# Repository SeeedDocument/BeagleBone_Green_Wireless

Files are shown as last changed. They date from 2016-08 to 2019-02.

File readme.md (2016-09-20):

BeagleBone Green Wireless
---

**SKU**: [102010048](http://www.seeedstudio.com/SeeedStudio-BeagleBone-Green-Wireless-p-2650.html)

**Wiki Link**: [wiki.seeed.cc](wiki.seeed.cc)

###Change Log:

- **2016-8-28:** update and create repos by Jerry Yip

--------
This document is written by Seeed Studio and is licensed under MIT License.

Contributing to this document is warmly welcomed. You can do this basically by
[forking](https://help.github.com/articles/fork-a-repo), committing modifications and then [pulling requests](https://help.github.com/articles/using-pull-requests) (follow the links above
for operating guide). Adding change log and your contact into file header is encouraged.
Thanks for your contribution.

Seeed is a hardware innovation platform for makers to grow inspirations into differentiating products. By working closely with technology providers of all scale, Seeed provides accessible technologies with quality, speed and supply chain knowledge. When prototypes are ready to iterate, Seeed helps productize 1 to 1,000 pcs using in-house engineering, supply chain management and agile manufacture forces. Seeed also team up with incubators, Chinese tech ecosystem, investors and distribution channels to portal Maker startups beyond.

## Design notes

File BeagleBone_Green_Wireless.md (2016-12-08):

---
title: BeagleBone Green Wireless
category: BeagleBone, IoT
bzurl: https://www.seeedstudio.com/SeeedStudio-BeagleBone-Green-Wireless-p-2650.html
oldwikiname: SeeedStudio_BeagleBone_Green_Wireless
prodimagename: BBGW_cover.png
surveyurl: https://www.surveymonkey.com/r/bbg_w
sku: 102010048
---

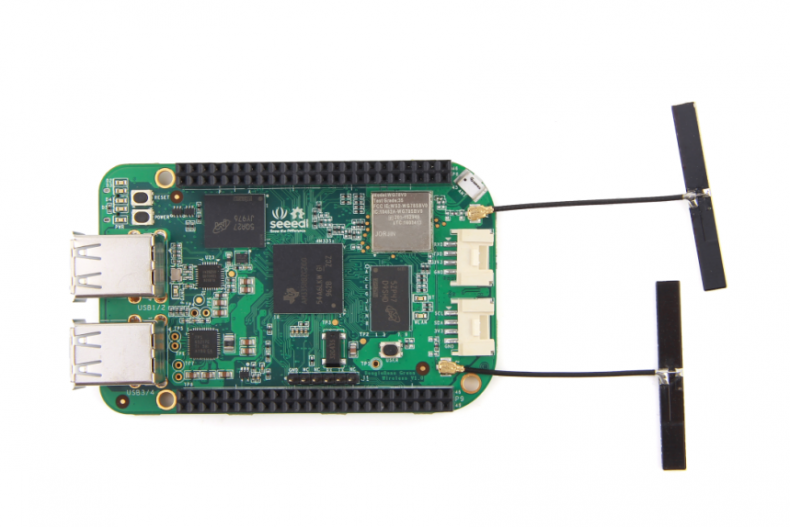
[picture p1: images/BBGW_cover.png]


SeeedStudio BeagleBone Green Wireless (BBGW) is a joint effort by [BeagleBoard.org](http://beagleboard.org) and Seeed Studio. It is based on the open-source hardware design of [BeagleBone Black](http://beagleboard.org/black) and developed into this differentiated version. SeeedStudio BeagleBone Green Wireless has included a high-performance flexible WiFi/Bluetooth interface and two Grove connectors, making it easier to connect to the large family of Grove sensors. The on-board HDMI and Ethernet are removed to make room for these wireless features and Grove connectors.

(http://www.seeedstudio.com/SeeedStudio-BeagleBone-Green-Wireless-p-2650.html)

## Features
----

* **Fully Compatiable with BeagleBone Black**
* **Processor: AM335x 1GHz ARM® Cortex-A8**
	* 512MB DDR3 RAM
	* 4GB 8-bit eMMC on-board flash storage
	* 3D graphics accelerator
	* NEON floating-point accelerator
	* 2x PRU 32-bit microcontrollers

* **Connectivity**
	* USB client for power & communications
	* USB host with 4-port hub
	* WiFi 802.11 b/g/n 2.4GHz
	* Bluetooth 4.1 with BLE
	* 2x 46 pin headers
	* 2x Grove connectors (I2C and UART)

* **Software Compatibility**
	* Debian
	* Android
	* Ubuntu
	* Cloud9 IDE on Node.js w/ BoneScript library
	* plus much more

## Specification
----

|Item|Value|
|----|---|
|Processor|	AM335x 1GHz ARMR Cortex-A8|
|RAM|	512MB DDR3|
|on-board Flash Storage	|4GB eMMC|
|CPU Supports	|NEON floating-point & 3D graphics accelerator|
|Micro USB	Supports |powering & communications|
|USB |USB2.0 Host	*4|
|Grove Connectors	|2 (One I2C and One UART) |
|GPIO	|2 x 46 pin headers|
|Ethernet	|Wi-Fi 802.11b/g/n 2.4GHz and Bluetooth 4.1 LE|
|Operating Temperature	|0 ~ 75 |

## Application Ideas
- Internet of Things
- Smart House
- Industrial
- Automation & Process Control
- Human Machine Interface
- Sensor Hub
- Robot

###BBGW Starter Tutorial #1-#6
Here are some tutorials for the starters to use some Grove modules to realize their interesting ideas with BeagleBone Green Wireless(BBGW). The tutorials are based on Python and mraa/upm library.  

|#1 The Breath LED|#2 Storm on your table|#3 Speak Louuuuuudly|
|---|-----|---|
||||
|[MAKE IT NOW!](http://www.seeed.cc/BBGW-starter-tutorial%231-The-breath-LED-p-1641.html)|[MAKE IT NOW!](http://www.seeed.cc/BBGW-starter-tutorial%232%3A-storm-on-your-table-p-1643.html)|[MAKE IT NOW!](http://www.seeed.cc/BBGW-starter-tutorial%233-Speak-louuuuuudly-p-1644.html)|

|#4 How hot is it today?|#5 Where are you?|#6 My Little alarm clock|
|---|-----|---|
||||
|[MAKE IT NOW!](http://www.seeed.cc/BBGW-starter-tutorial%234%3AHow-hot-is-it-today%3F-Ask-BBGW!-p-1645.html)|[MAKE IT NOW!](http://www.seeed.cc/BBGW-starter-tutorial%235-Where-are-you%3F-p-1648.html)|[MAKE IT NOW!](http://www.seeed.cc/BBGW-starter-tutorial%236-My-little-alarm-clock-p-1646.html)|

###Funny Projects

|Bluetooth Device Detection|Home Control Center|SAP HCP IoT Service|
|---|-----|---|
||||
|[MAKE IT NOW!](http://www.seeed.cc/Bluetooth-Device-Detection-with-the-BeagleBone-Green-Wireless-p-1601.html)|[MAKE IT NOW!](http://www.seeed.cc/Home-Control-Center-using-BeagleBone-Green-Wireless-p-1596.html)|[MAKE IT NOW!](http://www.seeed.cc/SAP-HCP-IOT-SERVICE-WITH-WIOLINK-p-1581.html)|

## Hardware Overview

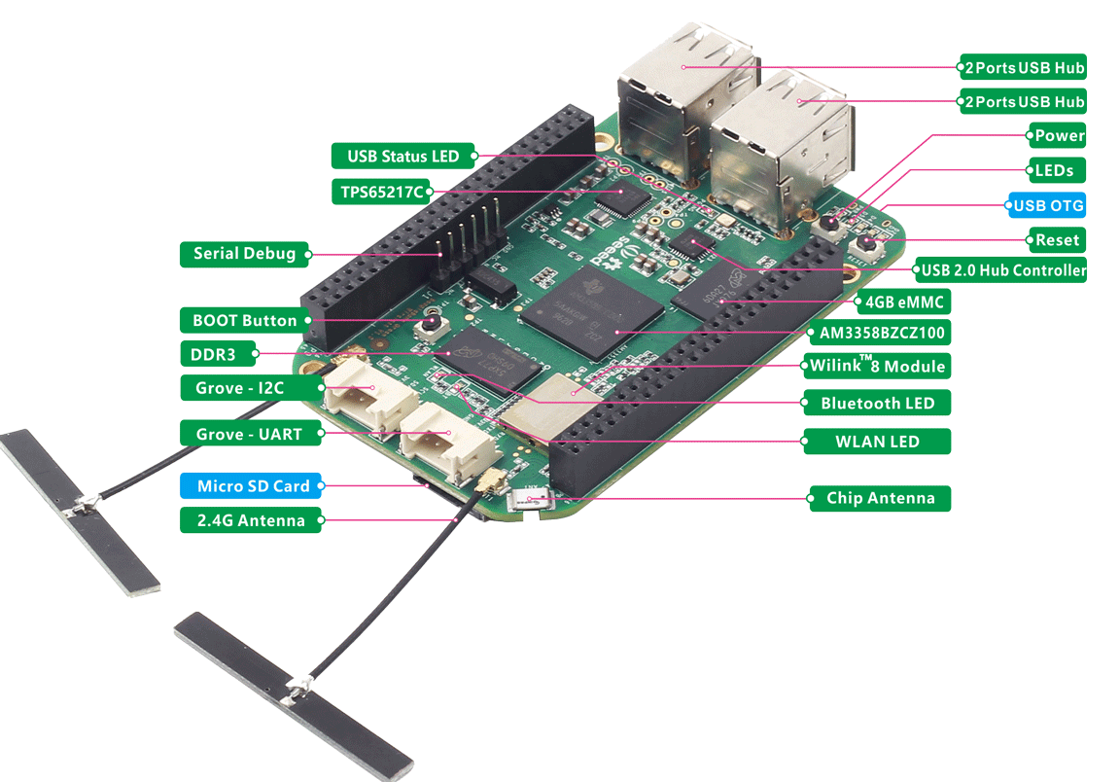
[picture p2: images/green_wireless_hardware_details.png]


###Pin map

Each digital I/O pin has 8 different modes that can be selected, including GPIO.

####65 Possible Digital I/Os

!!!Note
    In GPIO mode, each digital I/O can produce interrupts.

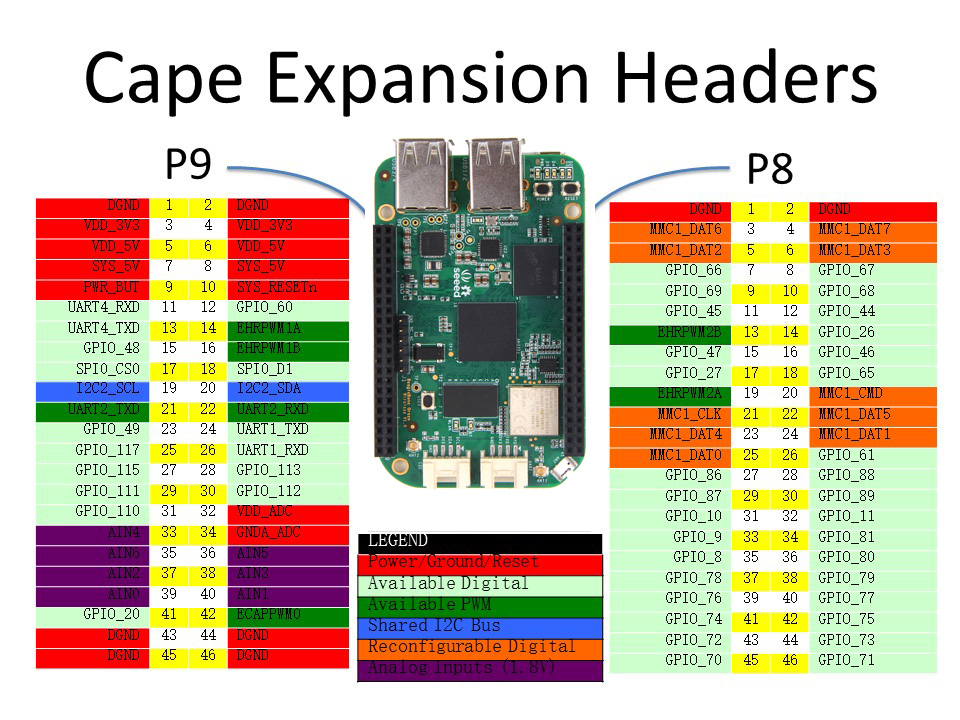
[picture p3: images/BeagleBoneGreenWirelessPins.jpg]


####PWMs and Timers

!!!Note
    Up to 8 digital I/O pins can be configured with pulse-width modulators (PWM) to produce signals to control motors or create pseudo analog voltage levels, without taking up any extra CPU cycles.

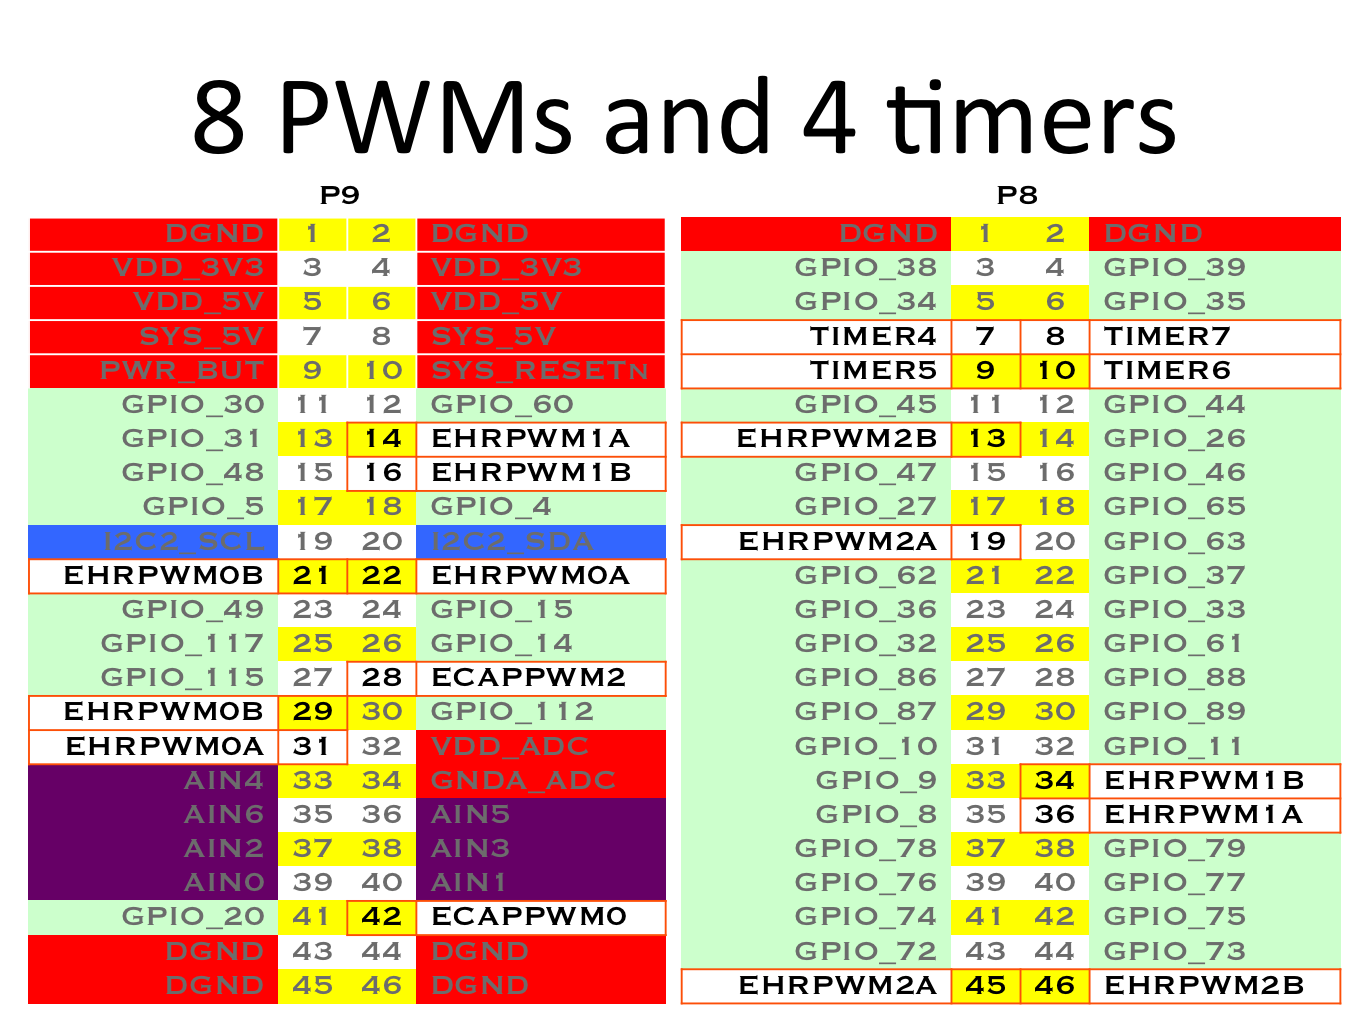
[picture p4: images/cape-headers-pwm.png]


####Analog Inputs

!!!Note
    Make sure you don't input more than 1.8V to the analog input pins. This is a single 12-bit analog-to-digital converter with 8 channels, 7 of which are made available on the headers.

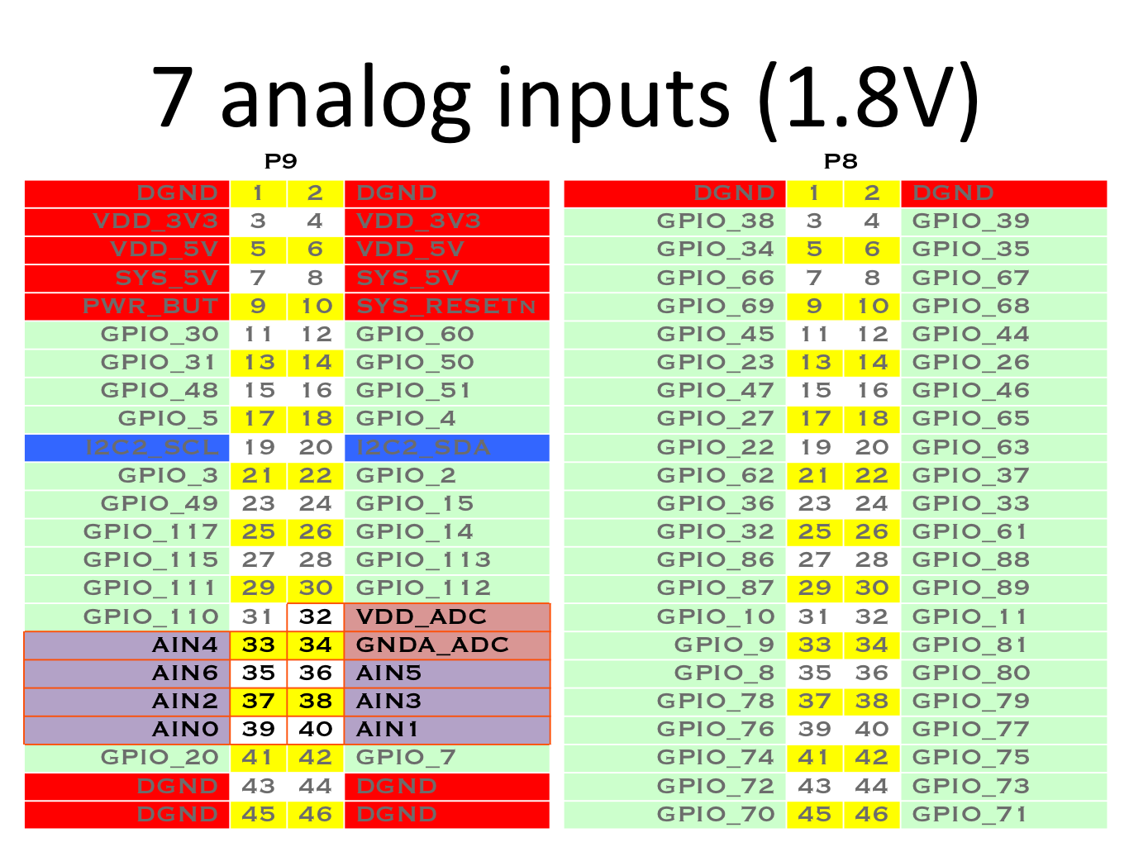
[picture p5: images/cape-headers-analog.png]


####UART

!!!Note
    There is a dedicated header for getting to the UART0 pins and connecting a debug cable. Five additional serial ports are brought to the expansion headers, but one of them only has a single direction brought to the headers.

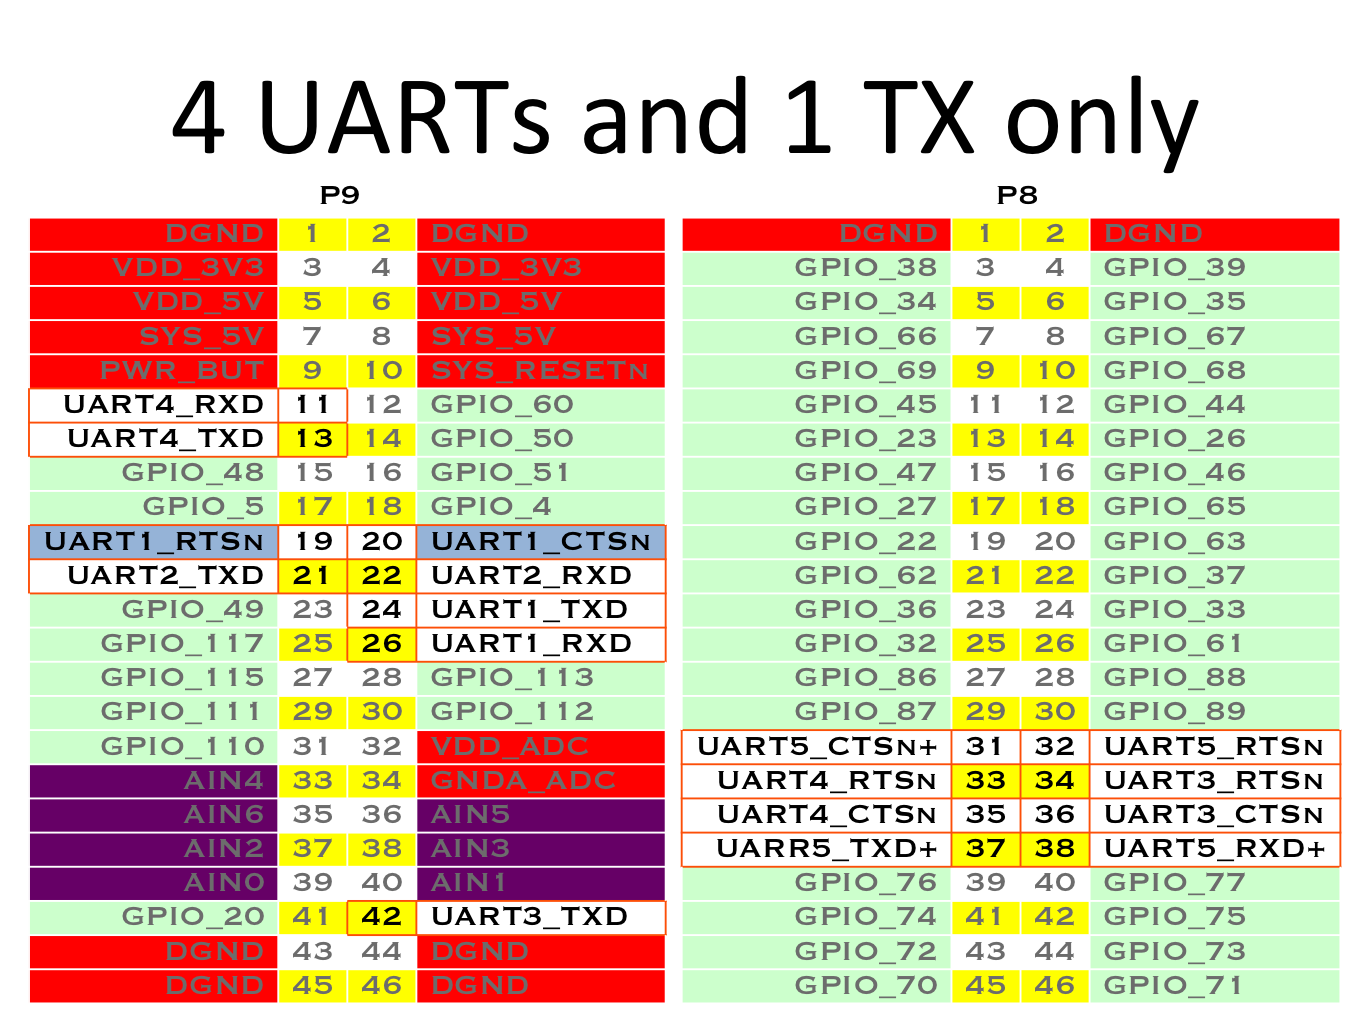
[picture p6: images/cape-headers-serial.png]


####I2C

!!!Note
    The first I2C bus is utilized for reading EEPROMS on cape add-on boards and can't be used for other digital I/O operations without interfering with that function, but you can still use it to add other I2C devices at available addresses. The second I2C bus is available for you to configure and use.

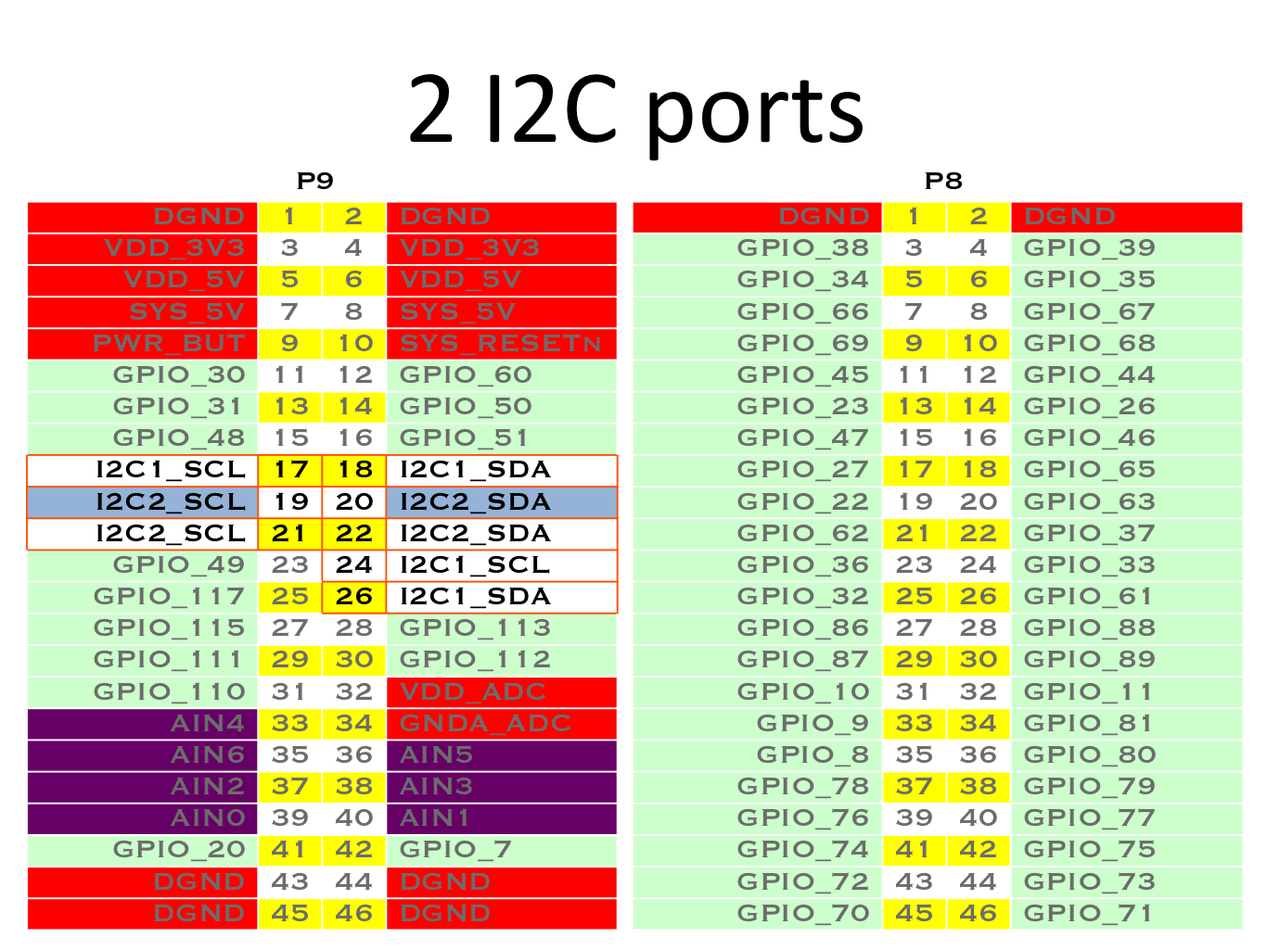
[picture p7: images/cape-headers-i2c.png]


####SPI

!!!Note
    For shifting out data fast, you might consider using one of the SPI ports.

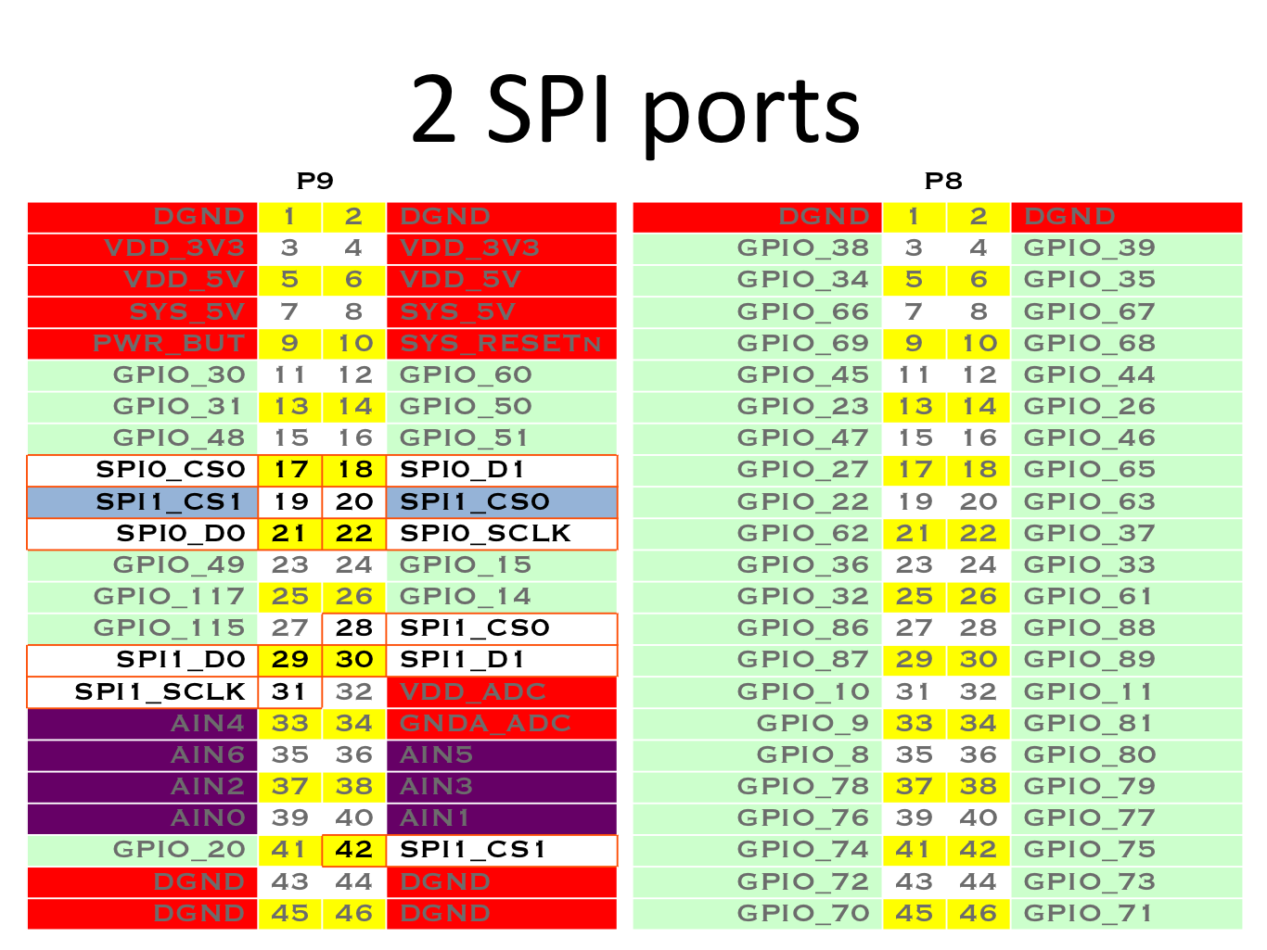
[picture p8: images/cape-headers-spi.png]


## Getting Started
----

!!!Note
    This chapter is writing under Win10. The steps are familiar for the other operate systems.

###STEP1. Plug in your BBGW via USB
Use the provided micro USB cable to plug your BBGW into your computer. This will both power the board and provide a development interface. BBGW will boot Linux from the **on-board 2GB** or 4GB eMMC.

BBGW will operate as a flash drive providing you with a local copy of the documentation and drivers. Note that this interface may not be used to re-configure the microSD card with a new image, but may be used to update the boot parameters using the uEnv.txt file.

You’ll see the PWR LED lit steadily. Within 10 seconds, you should see the other LEDs blinking in their default configurations.

- D2 is configured at boot to blink in a heartbeat pattern
- D3 is configured at boot to light during microSD card accesses
- D4 is configured at boot to light during CPU activity
- D5 is configured at boot to light during eMMC accesses

###STEP2. Install Drivers

Install the drivers for your operating system to give you network-over-USB access to your Beagle. Additional drivers give you serial access to your board.

|Operating System |	USB Drivers |	Comments |
|---|---|---|
|Windows (64-bit) |	[64-bit installer](http://beagleboard.org/static/Drivers/Windows/BONE_D64.exe)	 | |
|Windows (32-bit) |	[32-bit installer](http://beagleboard.org/static/Drivers/Windows/BONE_DRV.exe)||
|Mac OS X|[Network](http://beagleboard.org/static/Drivers/MacOSX/RNDIS/HoRNDIS.pkg) [Serial](http://beagleboard.org/static/Drivers/MacOSX/FTDI/EnergiaFTDIDrivers2.2.18.pkg) | Install both sets of drivers.|
|Linux|[mkudevrule.sh](http://beagleboard.org/static/Drivers/Linux/FTDI/mkudevrule.sh)|Driver installation isn't required, but you might find a few udev rules helpful.|

!!!Note
    For window system, please note that:

    * Windows Driver Certification warning may pop up two or three times. Click "Ignore", "Install" or "Run"
    * To check if you're running 32 or 64-bit Windows see [this](https://support.microsoft.com/kb/827218).
    *  On systems without the latest service release, you may get an error (0xc000007b). In that case, please [install](https://www.microsoft.com/en-us/download/confirmation.aspx?id=13523) and retry:
    * You may need to reboot Windows.
    * These drivers have been tested to work up to Windows 10

###STEP3. Browse to your Beagle

Using either Chrome or Firefox (Internet Explorer will NOT work), browse to the web server running on your board. It will load a presentation showing you the capabilities of the board. Use the arrow keys on your keyboard to navigate the presentation.

Click [http://192.168.7.2](http://192.168.7.2) to launch to your BBGW.
Older software images require you to EJECT the BEAGLE_BONE drive to start the network. With the latest software image, that step is no longer required.

Click to view larger image

###STEP4. Cloud9 IDE

To begin editing programs that live on your board, you can use the Cloud9 IDE by click

(http://192.168.7.2:3000/ide.html)

###STEP5. Connect your BBGW to Wi-Fi

Using your smart phone or computer to scan local Wi-Fi network and connect to the AP named "BeagleBone XXX"

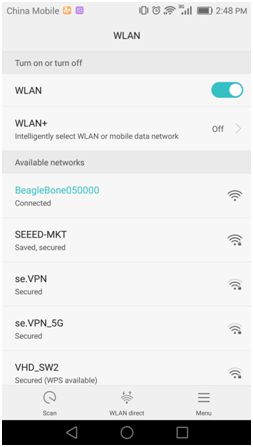
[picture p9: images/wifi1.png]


After connection succeeded, it will head to the login page automatically. Select the SSID of your Wi-Fi and enter the passwd, click OK.

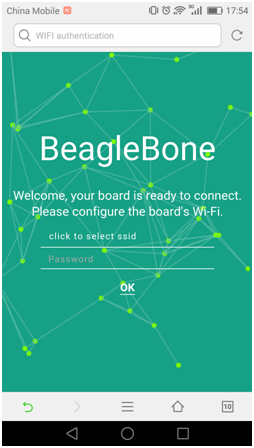
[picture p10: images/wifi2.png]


Now your BBGW is connected to Wi-Fi.

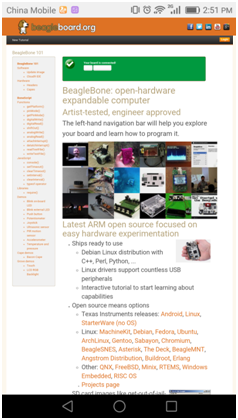
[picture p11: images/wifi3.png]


###STEP6. Connect your BBGW to your Bluetooth Device

Connect to Cloud9 IDE and start a new terminal.
Start the bluetooth config with the command:

```
bb-wl18x-bluetooth
bluetoothctl
```

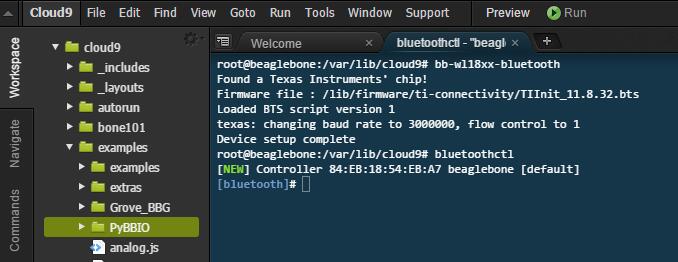
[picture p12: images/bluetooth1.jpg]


Type ``scan on`` to scan local bluetooth devices. My device named "jy" is found.

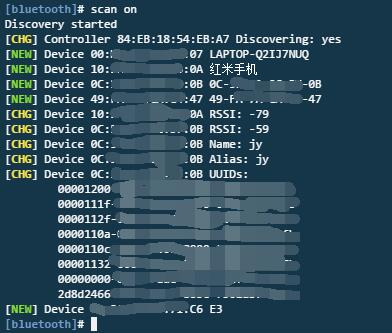
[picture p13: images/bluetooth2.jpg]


Copy the device mac address, then contect to the device  with the command:

```
pair 0C:xx:xx:xx:xx:0B
trust 0C:xx:xx:xx:xx:0B
connect 0C:xx:xx:xx:xx:0B
```

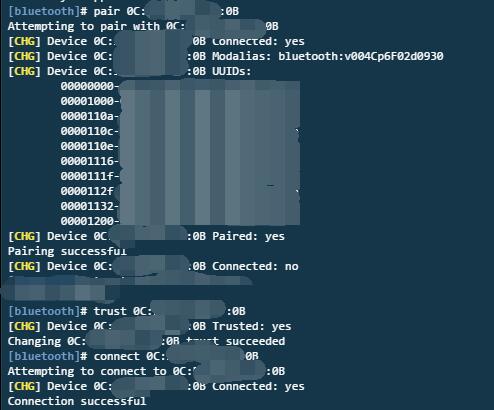
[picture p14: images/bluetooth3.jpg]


Now your BBGW is connected to your bluetooth device. Type ``quit`` back to the terminal.
Play music on BBGW, then you will hear music on your bluetooth speaker device.

## Update to latest software
-----

You need to update the board to latest software to keep a better performance, here we will show you how to make it step by step.

###STEP1. Download the latest software image

First of all, you have to download the suitable image here.

(https://www.dropbox.com/s/9qsa75cazhjgb1x/BBGW-blank-debian-8.4-seeed-iot-armhf-2016-06-27-4gb1.zip?dl=0)

!!!Note
    Due to sizing necessities, this download may take about 30 minutes or more.

The file you download will have an **.img.xz** extension. This is a compressed sector-by-sector image of the SD card.

###STEP2. Install compression utility and decompress the image

Download and install [7-zip.](http://www.7-zip.org/download.html)

!!!Note
    Choose a version that suitable for your system.

Use 7-zip to decompress the SD card **.img file**

###STEP3. Install SD card programming utility

Download and install [Image Writer for Windows](https://sourceforge.net/projects/win32diskimager/files/latest/download). Be sure to download the binary distribution.

###STEP4. Write the image to your SD card

You need a SD adapter to connect your microSD card to your computer at the first. Then use the software Image Write for Windows to write the decompressed image to your SD card.



Click on **Write** button, then the process is started.



!!!Note
    * You may see a warning about damaging your device. This is fine to accept as long as you are pointing to your SD card for writing.
    * You should not have your BeagleBone connected to your computer at this time.
    * This process may need up to 10 minutes.

###STEP5. Boot your board off of the SD card

Insert SD card into your (powered-down first) board. Then the board will boot from the SD card.

!!!Note
    If you don't need to write the image to your on-board eMMC, you don't need to read the last of this chapter.  Otherwise pleas go ahead.

If you desire to write the image to your on-board eMMC, you need to launch to the board, and modify a file.

In **/boot/uEnv.txt**:

    ##enable Generic eMMC Flasher:
    ##make sure, these tools are installed: dosfstools rsync
    #cmdline=init=/opt/scripts/tools/eMMC/init-eMMC-flasher-v3.sh
    
Change to:

    ##enable Generic eMMC Flasher:
    ##make sure, these tools are installed: dosfstools rsync
    cmdline=init=/opt/scripts/tools/eMMC/init-eMMC-flasher-v3.sh

Then you will find the 4 user led light as below:



!!!Note
    If you don't find the upper tracing light, please power down and power up the board.

When the flashing is complete, all 4 USRx LEDs will be **off**. The latest Debian flasher images automatically power down the board upon completion. This can take up to **10 minutes**. Power-down your board, remove the SD card and apply power again to be complete.

## Program Grove Module with Mraa and UPM

We have provided Mraa library and UPM library to make it easy for developers and sensor manufacturers to map their sensors & actuators on top of supported hardware and to allow control of low level communication protocol by high level languages & constructs.
###What are Mraa and UPM?
Mraa is a C/C++ library with bindings to Python, Javascript and Java to interface with the I/O on BBG, BBGW and other platforms, with a structured and sane API where port names/numbering matches the board that you are on. Use of Mraa does not tie you to specific hardware with board detection done at runtime you can create portable code that will work across the supported platforms.
UPM is a high level repository for sensors that use MRAA. Each sensor links to MRAA and are not meant to be interlinked although some groups of sensors may be. Each sensor contains a header which allows to interface with it. Typically a sensor is represented as a class and instantiated.The constructor is expected to initialise the sensor and parameters may be used to provide identification/pin location on the board.

###Install and update
Mraa and UPM are already installed in the system image of BBGW, so **you don't need to install it.** However if you want to update the library, or want to upgrade the library, use ``apt-get update`` and ``apt-get upgrade`` please. Refer to [https://github.com/intel-iot-devkit/mraa](https://github.com/intel-iot-devkit/mraa) and [https://github.com/intel-iot-devkit/upm](https://github.com/intel-iot-devkit/upm) for more information.

###Mraa Example

- light a led

```
import mraa
import time
#mraa.gpio60 = P9_14 = GPIO_50
led = mraa.Gpio(60)
led.dir(mraa.DIR_OUT)

while True:
    led.write(1)
    time.sleep(1)
    led.write(0)
    time.sleep(1)

```

- Grove - PIR Sensor

```
import mraa
import time
#mraa.gpio73 = P9_27 = GPIO_115
pir = mraa.Gpio(73)
pir.dir(mraa.DIR_IN)

while True:
    print (pir.read())
    time.sleep(1)
```

- Grove - Rotary Angle Sensor

```
import mraa
import time
#mraa.aio1 = AIN0
rotary = mraa.Aio(1)

while True:
    print(rotary.read())
    time.sleep(1)
```

- More Tutorials

[Grove - 3-Axis Digital Accelerometer(±16g)
 Grove - Variable Color LED](http://www.seeed.cc/BBGW-starter-tutorial%231-The-breath-LED-p-1641.html)

[Grove - Mini Fan
Grove - PIR Motion Sensor
Grove - Rotary Angle Sensor
](http://www.seeed.cc/BBGW-starter-tutorial%232%3A-storm-on-your-table-p-1643.html)

[Grove - Relay
Grove - Sound Sensor
](http://www.seeed.cc/BBGW-starter-tutorial%233-Speak-louuuuuudly-p-1644.html)

[Grove - OLED Display 0.96”
Grove - Light Sensor
Grove - Temperature Sensor
](http://www.seeed.cc/BBGW-starter-tutorial%234%3AHow-hot-is-it-today%3F-Ask-BBGW!-p-1645.html)

[Grove - GPS
Grove - Button(P)
Grove - Buzzer
Grove - RTC v2.0
](http://www.seeed.cc/BBGW-starter-tutorial%235-Where-are-you%3F-p-1648.html)

###Mraa Map for BBGW

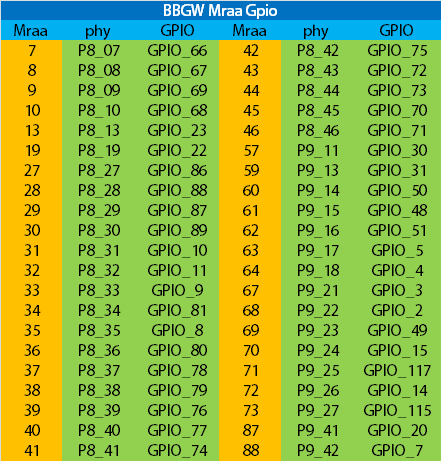
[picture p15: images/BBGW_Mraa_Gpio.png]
GPIO


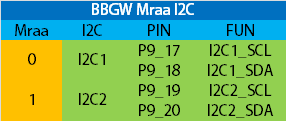
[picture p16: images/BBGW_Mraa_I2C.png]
I2C


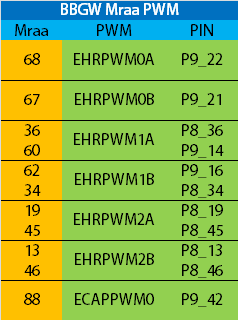
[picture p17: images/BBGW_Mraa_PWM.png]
PWM


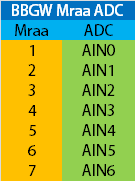
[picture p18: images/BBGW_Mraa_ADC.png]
ADC_IN


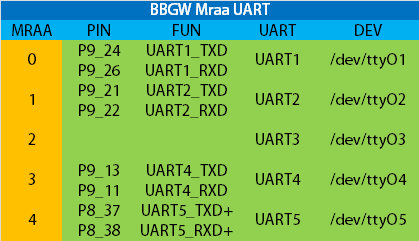
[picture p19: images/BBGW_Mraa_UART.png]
UART


## References and Resources
###References
----
There're many references to help you to get more information about the board.

* [BeagleBoard Main Page](http://beagleboard.org/)
* [BeagleBone Green Wireless info at BeagleBoard page](http://beagleboard.org/green-wireless)
* [BeagleBoard Getting Started](http://beagleboard.org/getting-started)
* [Troubleshooting](http://beagleboard.org/getting-started#troubleshooting)
* [Hardware documentation](http://beagleboard.org/getting-started#hardware)
* [Projects of BeagleBoard](http://beagleboard.org/project)

## Resources
-----
- [BeagleBone_Green_Wireless Schematic(pdf)](https://github.com/SeeedDocument/BeagleBone_Green_Wireless/tree/master/resources/BeagleBone_Green Wireless_V1.0_SCH_20160314.pdf)

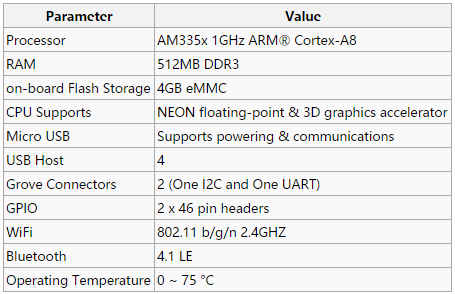
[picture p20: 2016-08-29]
images/BBGW_Specification.png

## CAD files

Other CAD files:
resources/BBGW_0421.skp

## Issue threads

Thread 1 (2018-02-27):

GPIO 60

comarius, 2018-02-27:
Bought 2 of them. They both put the GPIO_60 to 1 2 3 seconds after the prompt >

Boot it from eMMC, and then from SDcard (same behavior).

git:/opt/scripts/:[ea6ea9fca05f36f5044398884375b0231348d6e2]
eeprom:[A335BNLTGW1ABBGW16054396]
model:[TI_AM335x_BeagleBone_Green_Wireless]
dogtag:[BeagleBoard.org Debian Image 2018-01-28]
bootloader:[microSD-(push-button)]:[/dev/mmcblk0]:[U-Boot 2018.01-00002-g9aa111a004]
kernel:[4.9.78-ti-r94]
uboot_overlay_options:[enable_uboot_overlays=1]
uboot_overlay_options:[disable_uboot_overlay_emmc=1]
uboot_overlay_options:[disable_uboot_overlay_video=1]
uboot_overlay_options:[disable_uboot_overlay_audio=1]
uboot_overlay_options:[enable_uboot_cape_universal=1]
pkg:[bb-cape-overlays]:[4.4.20180126.0-0rcnee0~stretch+20180126]
pkg:[bb-wl18xx-firmware]:[1.20170829-0rcnee2~stretch+20180104]
pkg:[firmware-ti-connectivity]:[20170823-1rcnee0~stretch+20170830]
groups:[debian : debian adm kmem dialout cdrom floppy audio dip video plugdev users systemd-journal i2c bluetooth netdev cloud9ide gpio pwm eqep admin spi tisdk weston-launch xenomai]
dmesg | grep pinctrl-single
[    1.489922] pinctrl-single 44e10800.pinmux: 142 pins at pa f9e10800 size 568
END

me@beaglebone:/sys/class/gpio$ ls gpio6*
me@beaglebone:/sys/class/gpio$ find -name gpio60

me@beaglebone:/sys/class/gpio$ config-pin -l P9_60
Invalid pin: "P9_60" "9_60"
Pin is not modifyable: P9_60
# the one side of it works, all others work.
me@beaglebone:/sys/class/gpio$ config-pin -l P9_30
default gpio gpio_pu gpio_pd gpio_input spi pwm pruout pruin

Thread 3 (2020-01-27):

Missing schematic file !

salmanfarisvp, 2020-01-27:
Can't find the schematic file in the [https://github.com/SeeedDocument/BeagleBone_Green_Wireless/blob/master/resources/BeagleBone_Green%20Wireless_V1.0_SCH_20160314.pdf](https://github.com/SeeedDocument/BeagleBone_Green_Wireless/blob/master/resources/BeagleBone_Green%20Wireless_V1.0_SCH_20160314.pdf)

hulkco, 2020-01-27:
Hi @salmanfarisvp, I can see the PDF file.

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

salmanfarisvp, 2020-01-29:
I saw that but can't find the .sch eagle source file.

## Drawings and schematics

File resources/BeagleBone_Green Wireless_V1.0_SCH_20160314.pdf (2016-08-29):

1
3

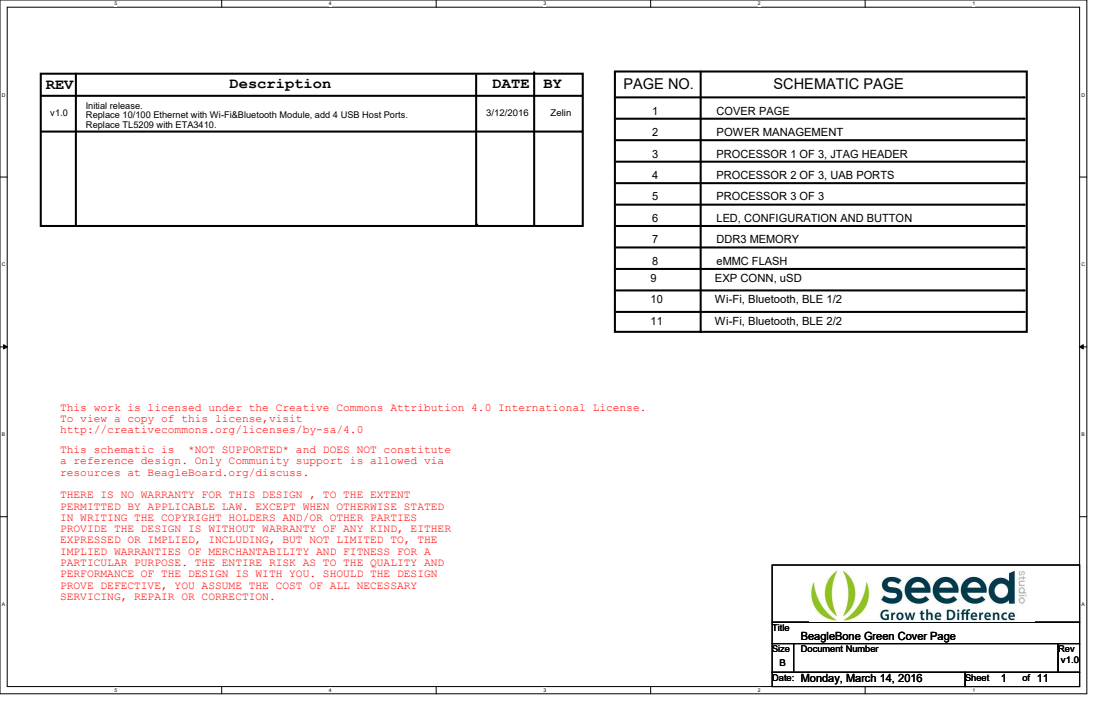
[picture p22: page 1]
eMMC FLASH; PAGE NO.; SCHEMATIC PAGE; REV; Description; DATE; Zelin; Title; Size Document Number; Rev; Date:; Sheet; BeagleBone Green Cover Page; Monday, March 14, 2016

Initial release.
Replace 10/100 Ethernet with Wi-Fi&Bluetooth Module, add 4 USB Host Ports.
Replace TL5209 with ETA3410.

COVER PAGE
POWER MANAGEMENT
PROCESSOR 1 OF 3, JTAG HEADER
PROCESSOR 2 OF 3, UAB PORTS
PROCESSOR 3 OF 3
LED, CONFIGURATION AND BUTTON
DDR3 MEMORY
EXP CONN, uSD
10 Wi-Fi, Bluetooth, BLE 1/2
11 Wi-Fi, Bluetooth, BLE 2/2

This work is licensed under the Creative Commons Attribution 4.0 International License.
To view a copy of this license,visit
http://creativecommons.org/licenses/by-sa/4.0
This schematic is *NOT SUPPORTED* and DOES NOT constitute
a reference design. Only Community support is allowed via
resources at BeagleBoard.org/discuss.
THERE IS NO WARRANTY FOR THIS DESIGN , TO THE EXTENT
PERMITTED BY APPLICABLE LAW. EXCEPT WHEN OTHERWISE STATED
IN WRITING THE COPYRIGHT HOLDERS AND/OR OTHER PARTIES
PROVIDE THE DESIGN IS WITHOUT WARRANTY OF ANY KIND, EITHER
EXPRESSED OR IMPLIED, INCLUDING, BUT NOT LIMITED TO, THE
IMPLIED WARRANTIES OF MERCHANTABILITY AND FITNESS FOR A
PARTICULAR PURPOSE. THE ENTIRE RISK AS TO THE QUALITY AND
PERFORMANCE OF THE DESIGN IS WITH YOU. SHOULD THE DESIGN
PROVE DEFECTIVE, YOU ASSUME THE COST OF ALL NECESSARY
SERVICING, REPAIR OR CORRECTION.

Title
BeagleBone Green Cover Page

# Battery access pins. Pins are randomly placed to fit

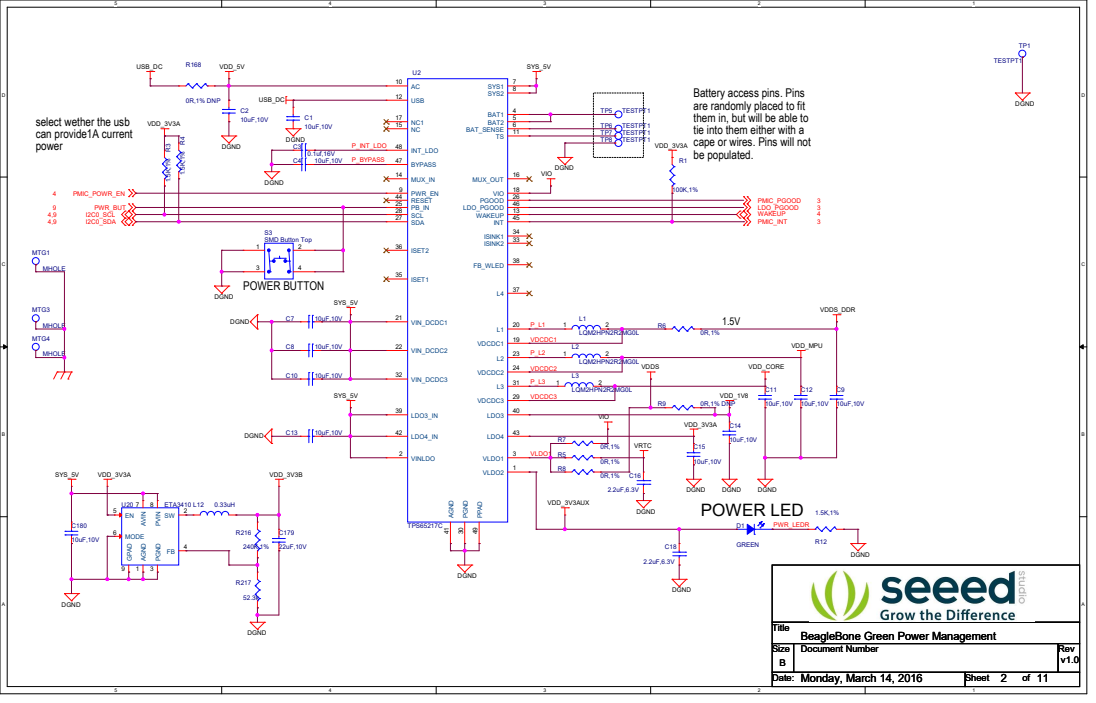
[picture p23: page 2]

them in, but will be able to
tie into them either with a
cape or wires. Pins will not
VDD_3V3A
be populated.

# RESET

3.3V

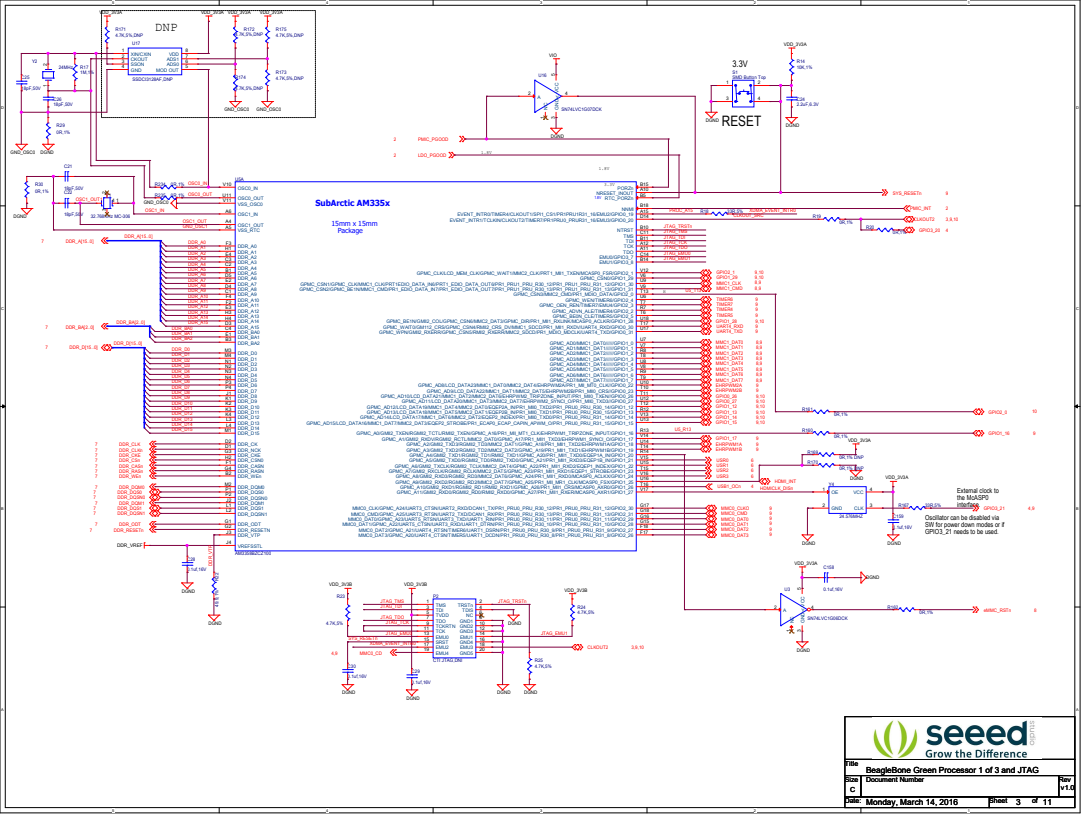
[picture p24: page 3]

PORZn B15 NRESET_INOUT A10 NNMI B18 EVENT_INTR0/TIMER4/CLKOUT1/SPI1_CS1/PR1PRU1R31_16/EMU2/GPIO0_19 A15 EVENT_INTR1/TCLKIN/CLKOUT2/TIMER7/PR1PRU0_PRUR31_16/EMU3/GPIO0_20 D14 TMS C11 NTRST B10 TCK A12 TDI B11 TDO A11 EMU0/GPIO3_7 C14 DDR_A0 F3 DDR_A1 H1 DDR_A2 E4 DDR_A3 C3 DDR_A4 C2 DDR_A5 B1 DDR_A6 D5 DDR_A7 E2 DDR_A8 D4 DDR_A9 C1 DDR_A10 F4 DDR_A11 F2 DDR_A12 E3 DDR_A13 H3 DDR_A14 H4 DDR_D0 M3 DDR_D1 M4 DDR_D2 N1 DDR_D3 N2 DDR_D4 N3 DDR_D5 N4 DDR_D6 P3 DDR_D7 P4 DDR_D8 J1 DDR_D9 K1 DDR_D10 K2 DDR_D11 K3 DDR_D12 K4 DDR_D13 L3 DDR_D14 L4 DDR_D15 M1 DDR_CK D2 DDR_NCK D1 DDR_CSN0 H2 DDR_CASN F1 DDR_RASN G4 DDR_WEn B2 DDR_BA0 C4 DDR_BA1 E1 DDR_BA2 B3 DDR_DQM0 M2 DDR_DQS0 P1 DDR_DQSN0 P2 DDR_DQM1 J2 DDR_DQS1 L1 DDR_DQSN1 L2 DDR_ODT G1

Oscillator can be disabled via
SW for power down modes or if
GPIO3_21 needs to be used.

# VDD_ADC GNDA_ADC

# VDD_3V3B DGND

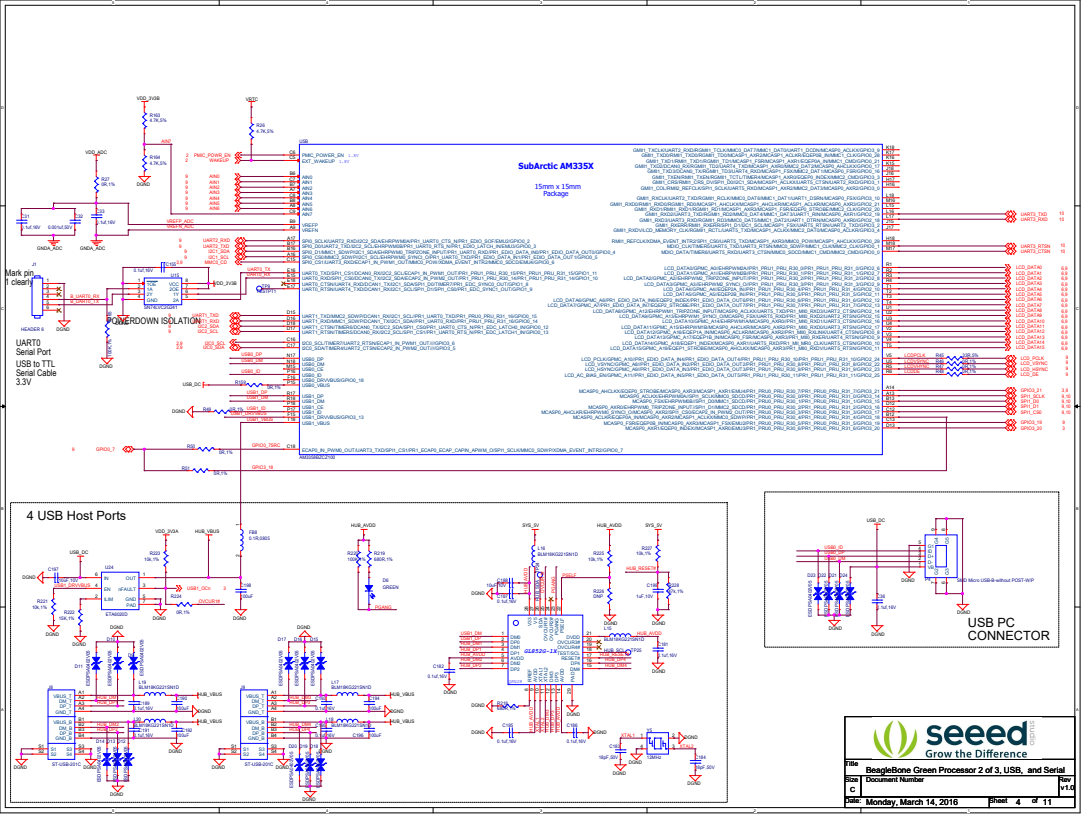
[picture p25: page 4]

9 XTAL1 10 XTAL2 11 DM3 12 DP3 13 AVDD 14 V33 28 V5 27 SDA 26 OVCUR1# 25 OVCUR2# 24 PGANG 23 PSELF 22 PAD 29

# 0.1uf,16V C38

# 0.1uf,16V C74

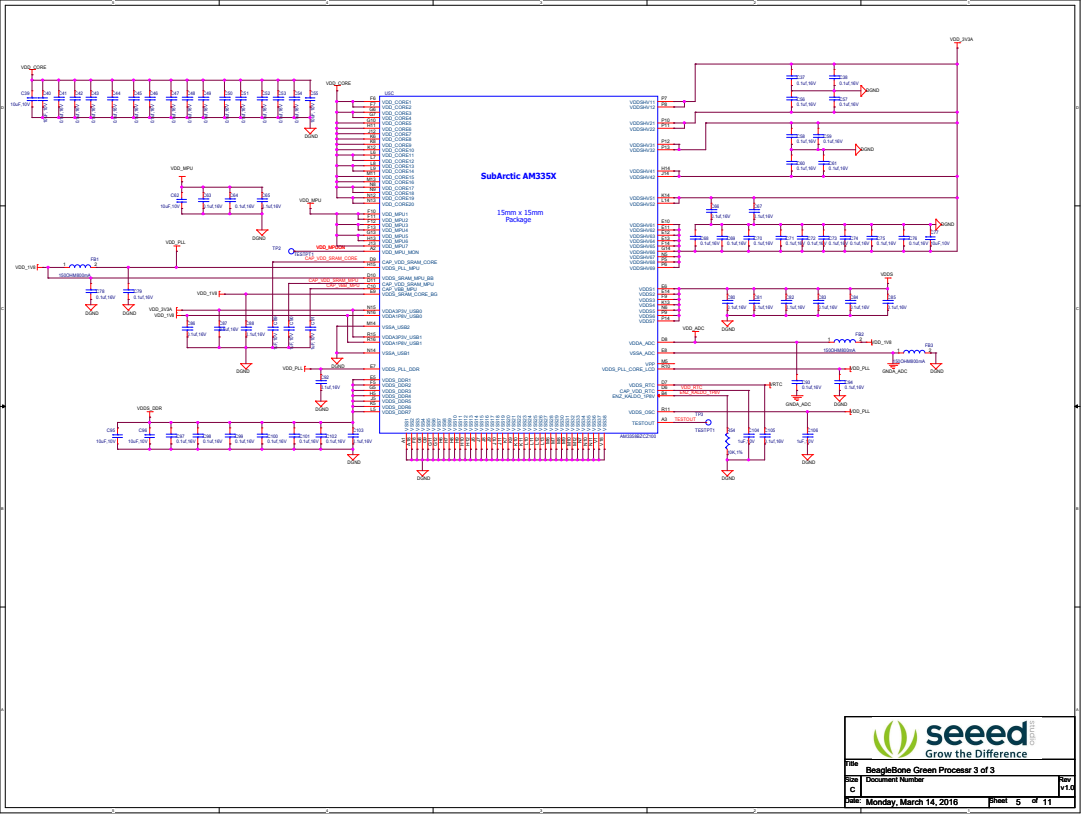
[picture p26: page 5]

## SYS_BOOT10

## SYS_BOOT4

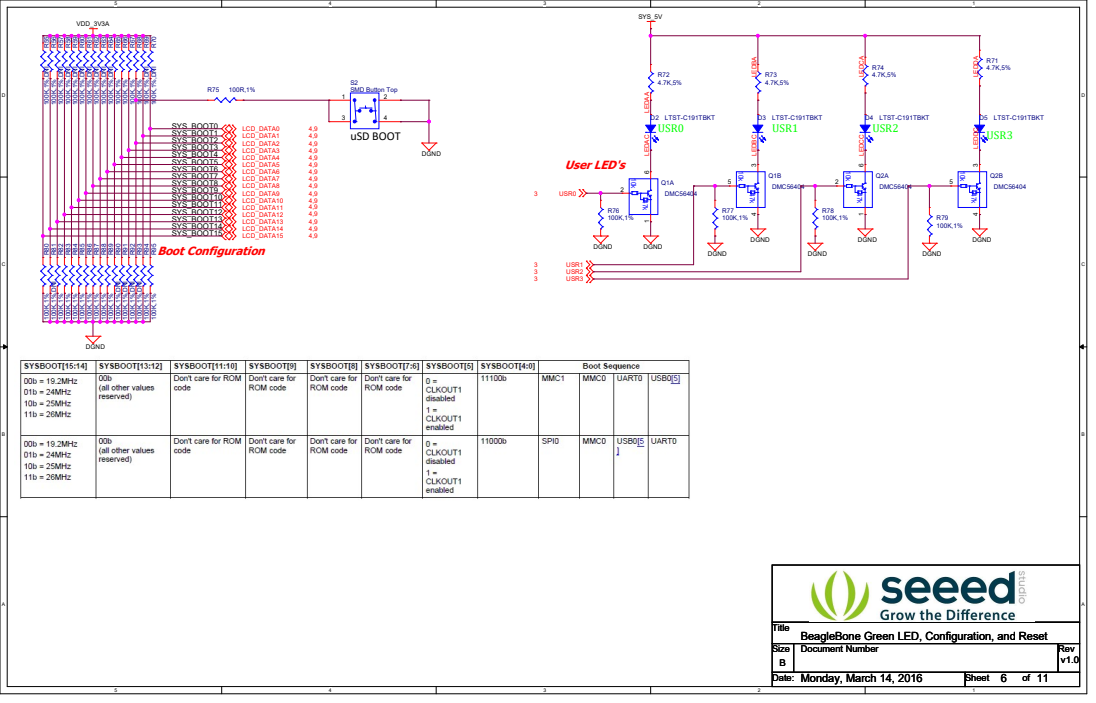
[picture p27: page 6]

SYS_BOOT5
SYS_BOOT6
SYS_BOOT7
SYS_BOOT8
SYS_BOOT9
SYS_BOOT11
SYS_BOOT12
SYS_BOOT13
SYS_BOOT14

Title
BeagleBone Green LED, Configuration, and Reset

# DDR3L SDRAM

## DGND

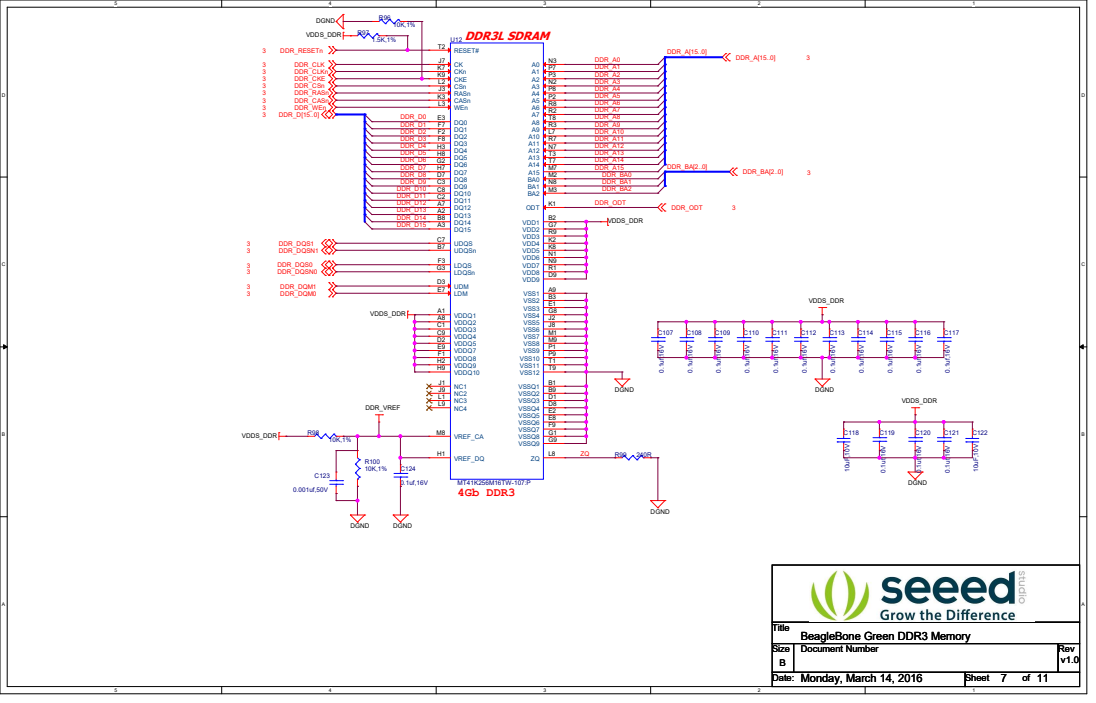
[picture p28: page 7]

## DGND DGND

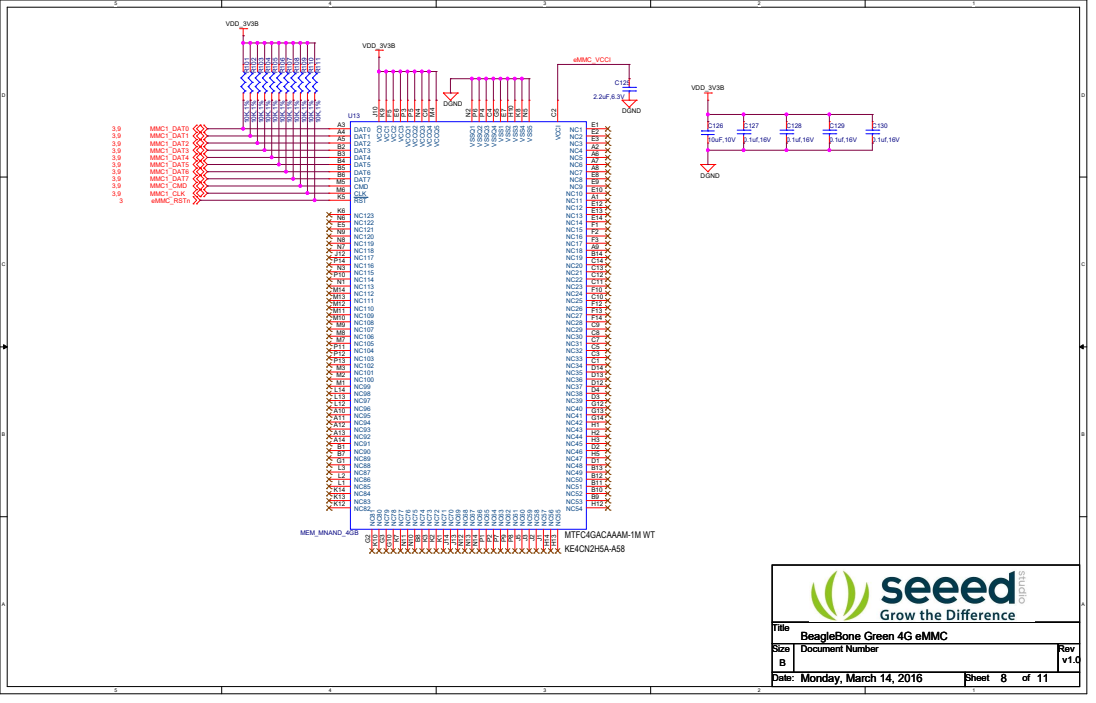
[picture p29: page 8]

uSD CONNECTOR CAUTION: USED ON BOARD | CAUTION: USED ON BOARD

## DGND

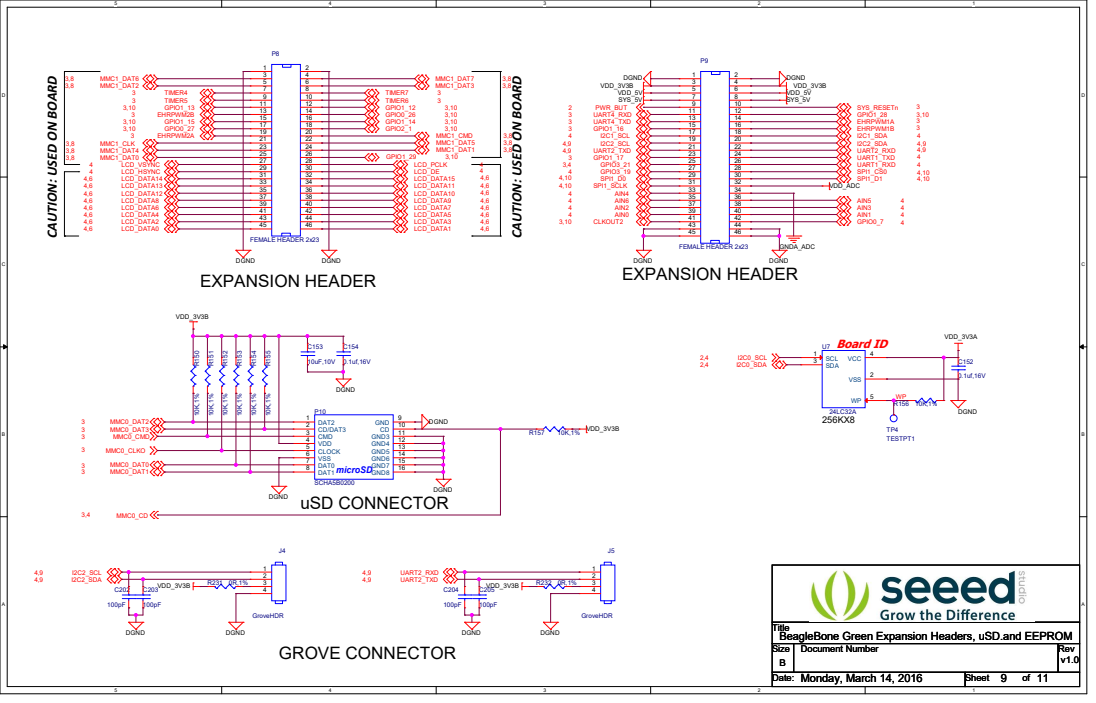
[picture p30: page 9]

Title
BeagleBone Green Expansion Headers, uSD.and EEPROM

## I2S_WCLK_OUT <--> SPI1_D0 I2S_BCLK_OUT <--> SPI1_SCLK

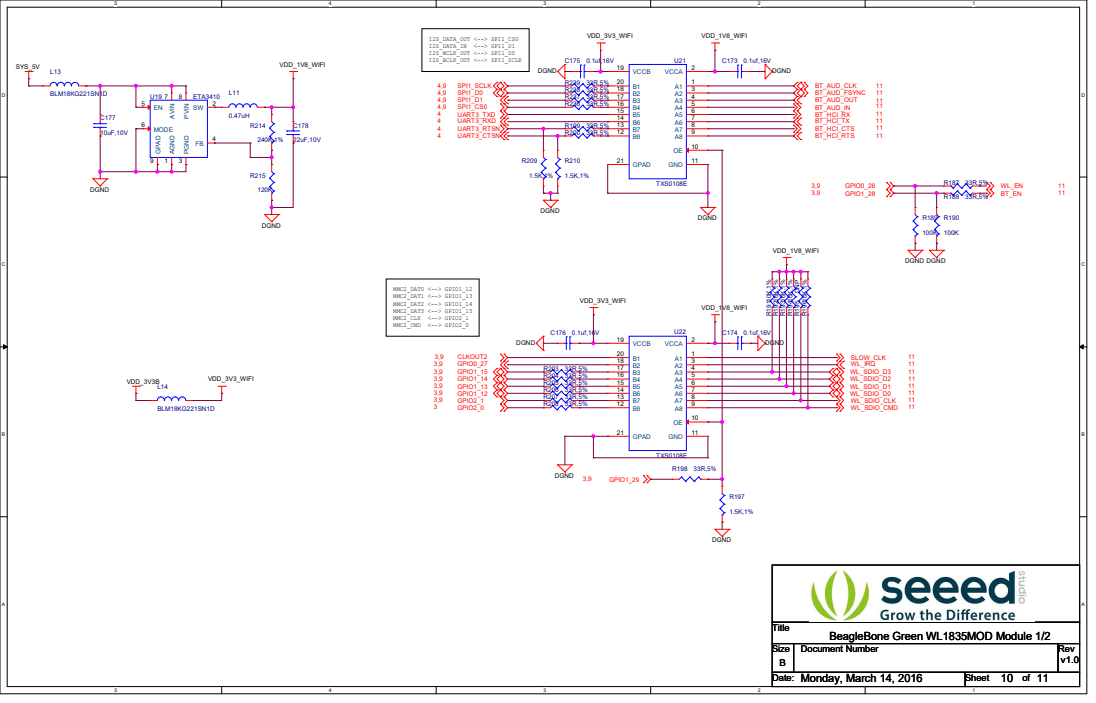
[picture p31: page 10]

### DGND

### DGND

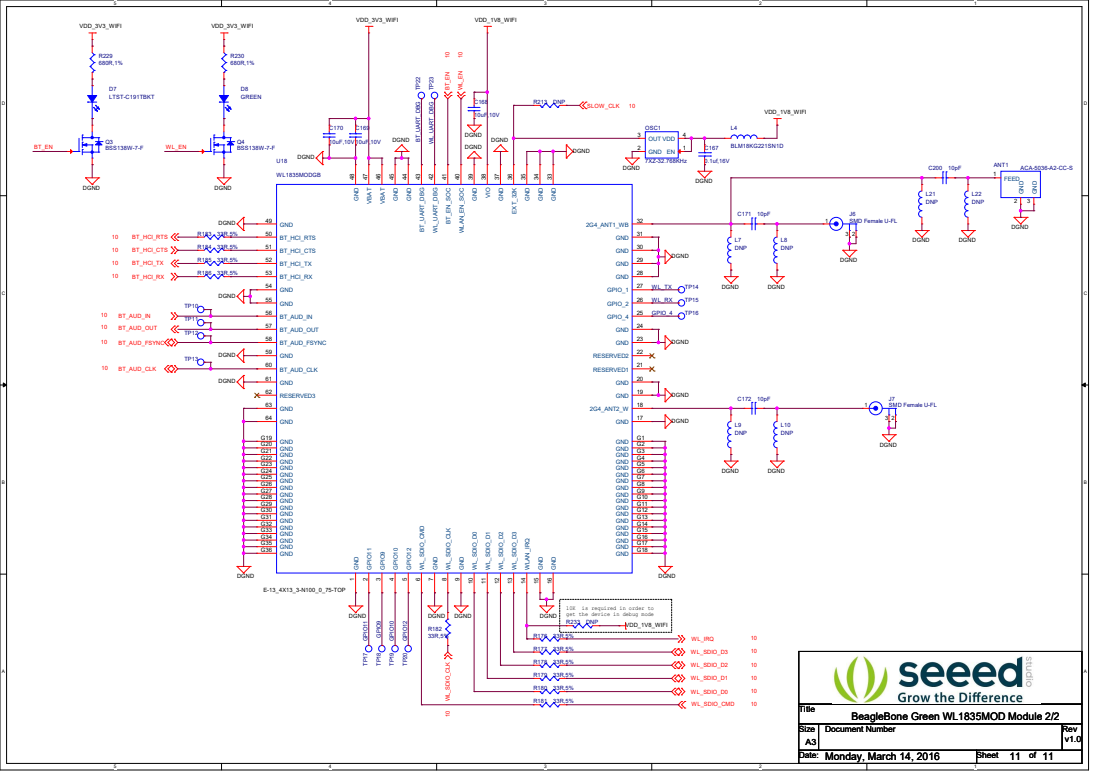
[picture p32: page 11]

7XZ-32.768KHz VDD 4 EN 1 GND 2 OUT 3

6 BT_HCI_RTS 50 BT_HCI_RX 53 BT_HCI_TX 52 BT_HCI_CTS 51 GND 16 GPIO_4 25 GPIO_2 26 GPIO_1 27 BT_EN_SOC 41 WLAN_IRQ 14 WLAN_EN_SOC 40 BT_UART_DBG 43 WL_UART_DBG 42 GND G13 GND G14 GND G15 GND G16 GND G9 GND G10 GND 48

GND G36
get the device in debug mode DGND

A A 10K is required in order to

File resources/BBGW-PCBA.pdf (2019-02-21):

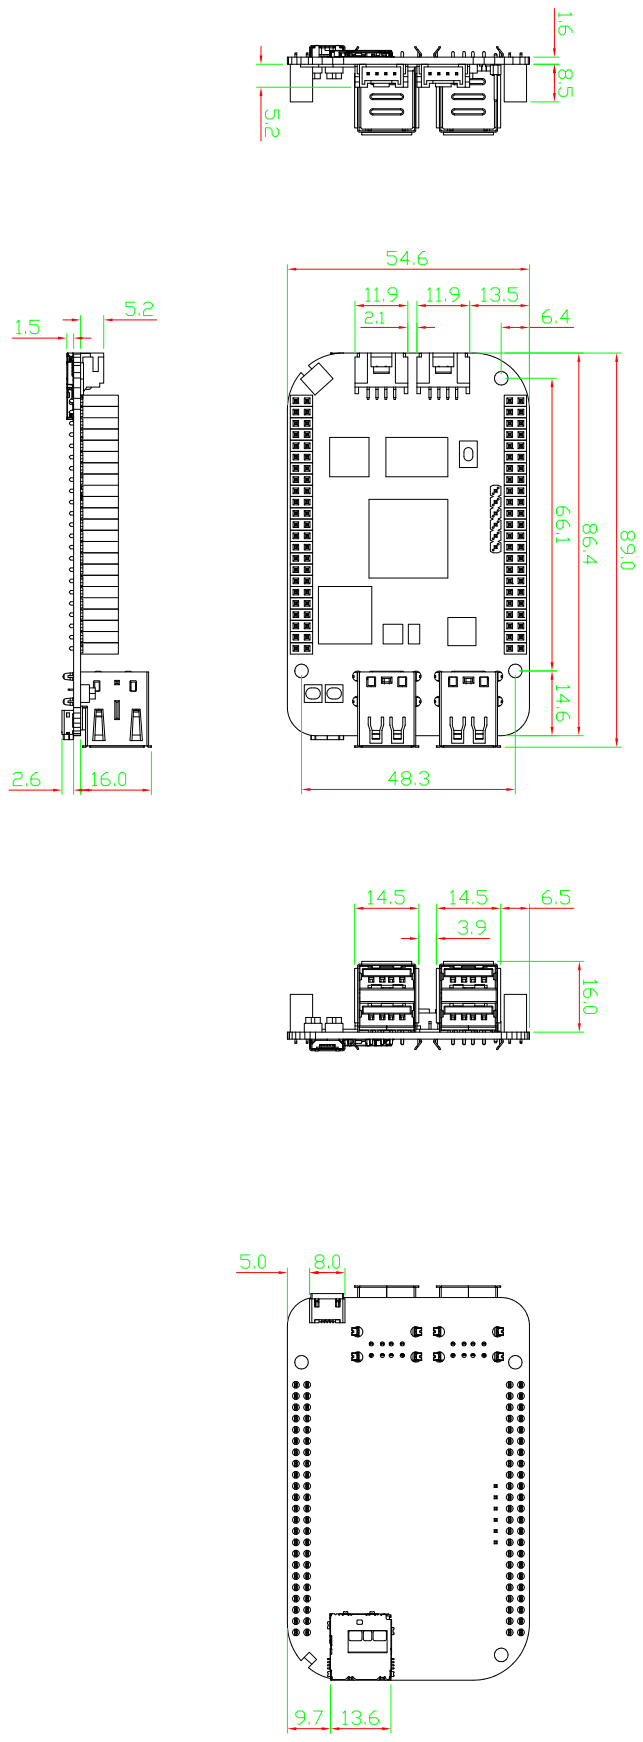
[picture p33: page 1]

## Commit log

2016-09-06 remove .md and mraa(gpio/pwm...).jpg
2016-10-26 add pcb&sch & fcc & ce
2019-02-12 add the 3d
    [BBGW_0421.skp]
